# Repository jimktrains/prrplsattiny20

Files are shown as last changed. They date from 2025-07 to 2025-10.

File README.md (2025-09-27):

PRR Position Light Signals based on an ATTiny20
-----------------------------------------------
Thumb for scale.

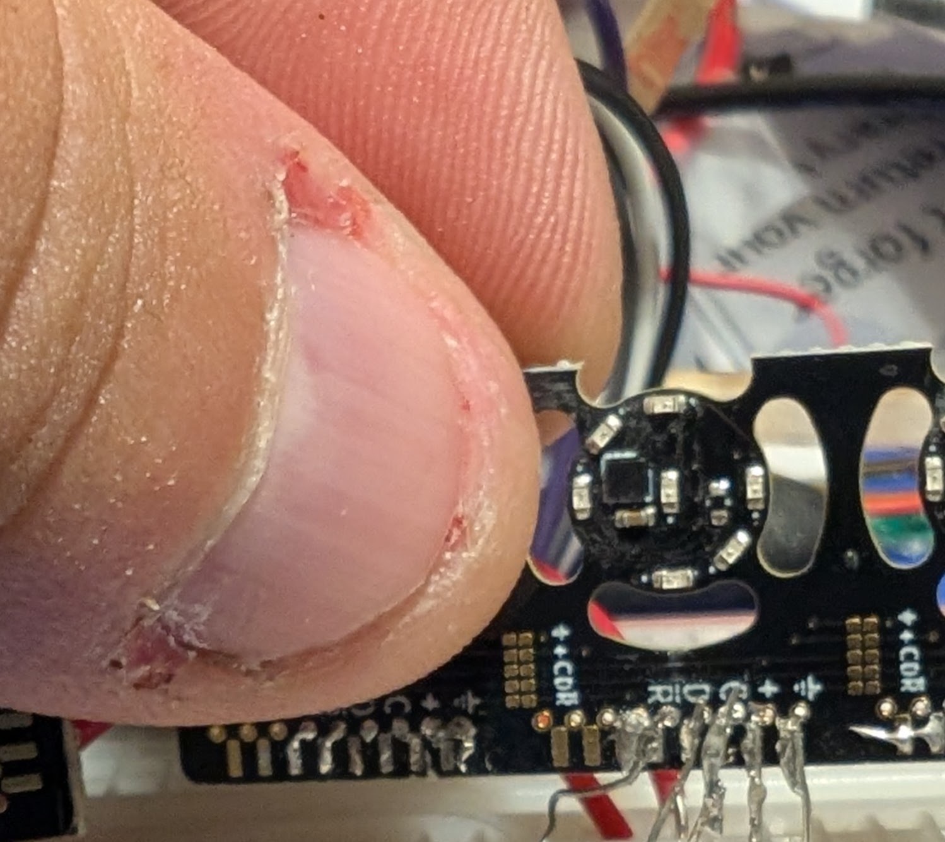
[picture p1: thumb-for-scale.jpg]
Thumb for scale


In Action!

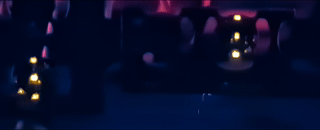
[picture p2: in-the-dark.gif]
In The Dark

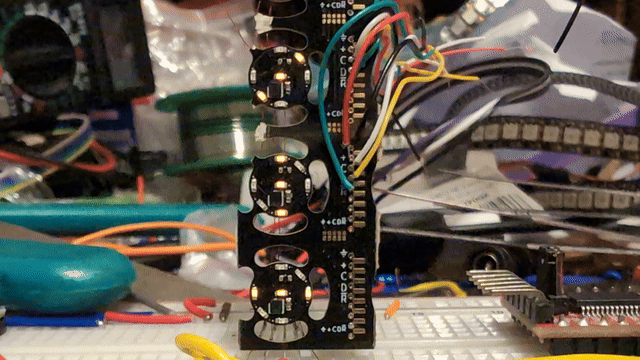
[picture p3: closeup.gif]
Close Up


The Pennsylvania Railroad (PRR), almost uniquely among railroads, used
Position Light Signals (PLS) 
[[1]](https://en.wikipedia.org/wiki/North_American_railroad_signals#Position_light_signals)
[[2]](https://railroadsignals.us/signals/pl/pl.htm). (The Norfolk & Western
used Colored Position Lights (CPL) 
[[2]]([https://railroadsignals.us/signals/pl/pl.htm) which were similar.)

I model [N-Scale](https://en.wikipedia.org/wiki/N_scale) which is 1:160
scale. From scans of PRR plans
[[3]](http://prr.railfan.net/signalstandards/standards.cgi?plan=S-401-D&frame=YES&sortdir=up&sortby=1&rr=all)
the diameter of the signal is 4'4", which becomes 0.325" (8.255mm) for the
scale model.

I've designed the system to use 3 wires: +5V, Ground, and Serial. Serial
data comes in, the first command extracted, and then the remainder of a packet
is retransmitted similar to how WS2812b / NeoPixels work. 

Protocol
========

The serial protocol is 
[Differential Manchester](https://en.m.wikipedia.org/wiki/Differential_Manchester_encoding)
, but kind of overlaid on
a double-baud UART frame, so it always starts with the "0" stop bit.

I moved to this from just a plain software UART as the timing on some of my
signals was off by a large enough amount to throw everything out of sync.
Decoding the differential Manchester packet is much less timing-sensitive.
It runs at 300baud/150bps with 4-bit packets.

A packet starts with an 0x4 followed a sequence of 0x3 for Stop, 0x2 for
Approach, and 0x1 for Clear, 0x0 for all lights off.

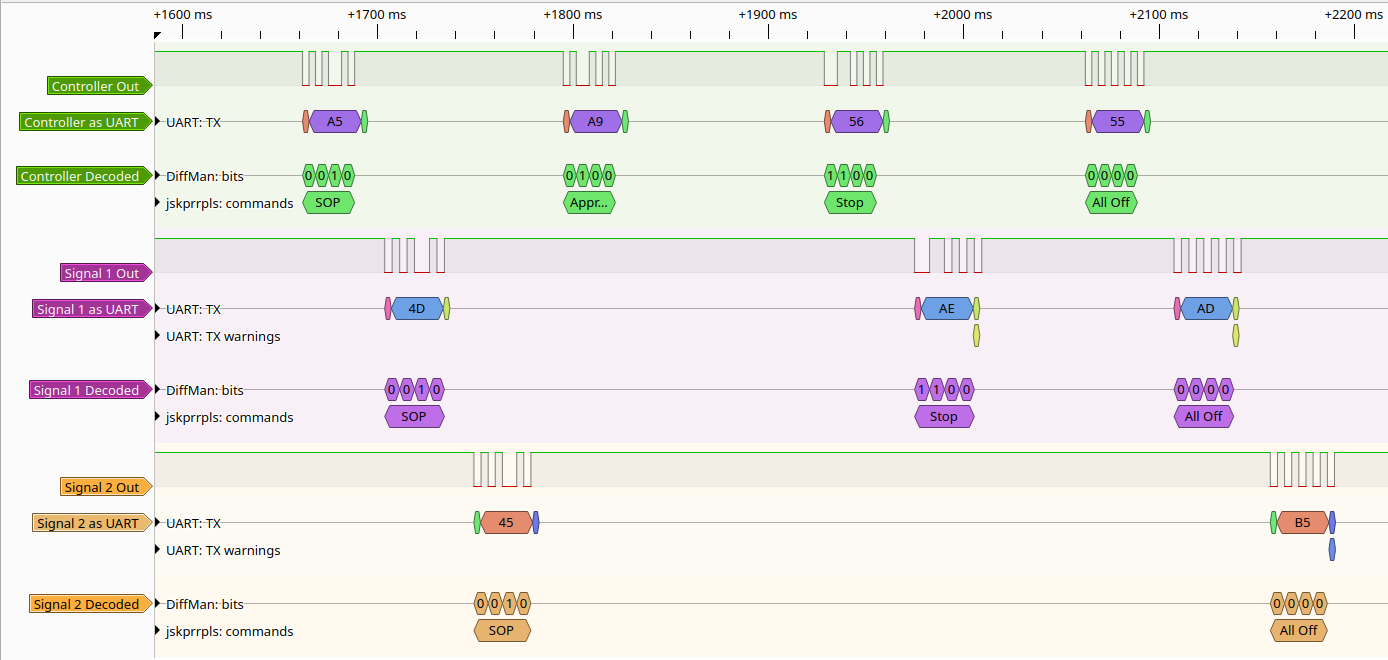
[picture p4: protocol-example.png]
Protocol Example


In this example, the controller sends out a 4-frame packet. Starting with a SOP (Start of Packet) frame, followed
by an Approach, then Stop, then All Off. The first signal dutifully forwards
the SOP frame. The second frame is for it, though, so it does not forward 
that one. The rest of the frames are for subsequent signals, so it forwards
all subsequent frames until a SOP is encountered again. The second signal
does as the first. It forwards the SOP, keeps the frame following the SOP,
and forwards any remaining frames until another SOP is encountered.

Also, note how when interpreted as a UART, the packets coming from the signals
isn't in sync with the baudrate. I'm sure that there's some way to get a more
stable clock on the μC, but it was significantly easier for me to switch to a
more forgiving line coding. 

There also needs to be at least a 20 symbol pause between frames sent. I 
think this has to do with how I decode the frame, but it deserves to be
looked at.

(The visualization is from PulseView/sigrok. I wrote a custom protocol
decoder to help me debug.)

Schematics / PCB
================

### General Notes

I am using an 
[ATTiny20](https://ww1.microchip.com/downloads/en/DeviceDoc/Atmel-8235-8-bit-AVR-Microcontroller-ATtiny20_Datasheet.pdf)
in a 
[WLCSP](https://en.wikipedia.org/wiki/Wafer-level_packaging) package 
(1.56mm&times;1.4mm) with 0.4mm balls, and I'm not sure I can solder that
at my current skill level.) I'm just bemused at it's physical size, even if
it only has 128 bytes of RAM. It fits perfectly in the area available,
allows for components on a single side, and has enough I/O to control
the LEDs individually.

In order to avoid having to place a resistor per
LED, I'm using the pull-up resistors in the microcontroller. Since these
are large-resistance resistors, it limits the brightness of the LEDs. While
the pull-up resistors aren't any specific resistance and can be pretty
variable, the ones within a single chip should be pretty similar. This may
mean that signals visibility near each other may be of different brightness,
but so far it doesn't appear to be a noticeable issue.

The limited brightness is a potential problem, but I'm going to try up the
effective PWM duty cycle. If each light is updated sequentially at the
frequency at which the RX pin is sampled spread over the 7 lights -- 
currently 1200Hz with a 1/7 (14%) duty cycle. Because the LEDs are
charliplexed I am limited in which LEDs I could turn on simultaneously.
However, because I separated out the center light and I think lucked into
arranging the lights in a sensible order I am able to have them on with
100% duty cycle for the 3 basic aspects these display (Stop, Clear, and
Approach). For those aspects I think the current brightness is adequate.

### PCB Notes

The PCB design is fairly simple, and using 4 layers (Signal, +5V+Minimal Signal,
GND, Signal) made routing easier.

To avoid using via-in-pads (and being charged accordingly), there are 3 pins
(balls?) that aren't used. If they had been used, each LED could have been
directly connected to the μC. As such, I was able to control the LEDs
individually by charlieplexing them.

I used a 1.27mm pitch SOIC chip clip as my connectorless connector. (I did
manage to make the through-holes a little too small, so it doesn't attach
as securely as I would have liked.) Eventually I just soldered some THT
resistor legs to these to connect to a breadboard for some of the signal
heads.

When panalized, I added some traces that I can use to interconnect columns
for testing.

### Individual Schematic

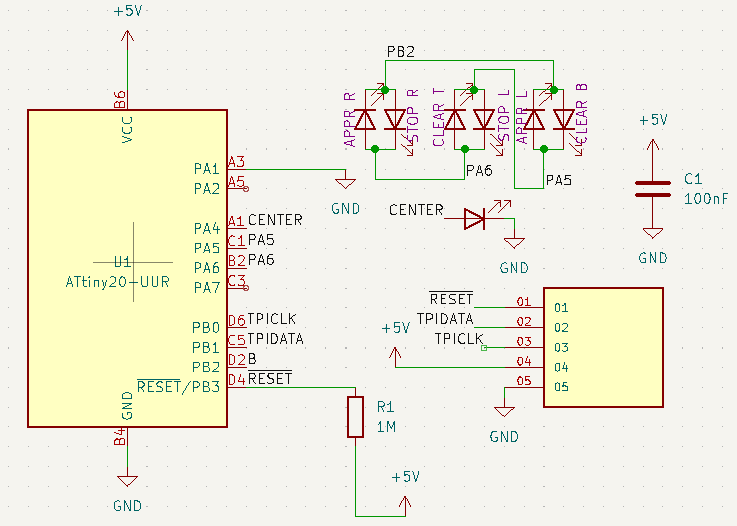
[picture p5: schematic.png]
Individual Schematic


### Front Copper

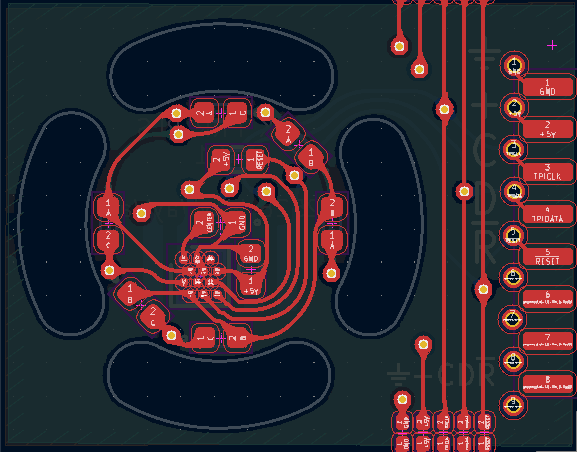
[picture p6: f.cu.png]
F.Cu


### Inner 1 Copper

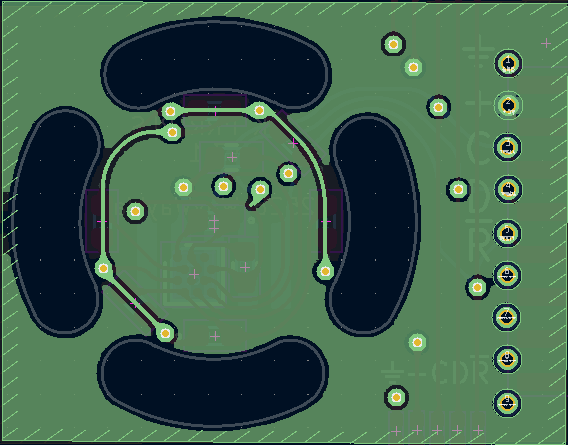
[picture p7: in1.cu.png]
In1.Cu


### Inner 2 Copper

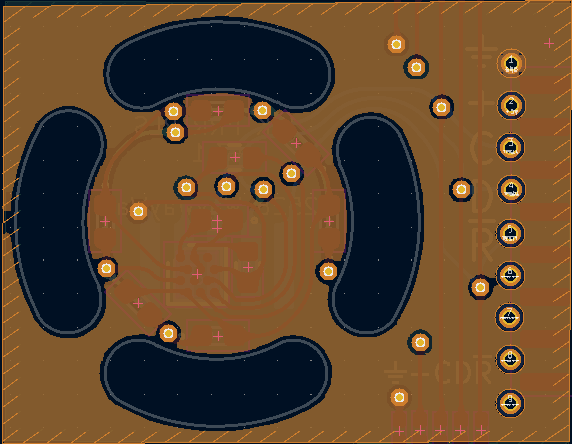
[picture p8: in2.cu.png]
In2.Cu


### Back Copper

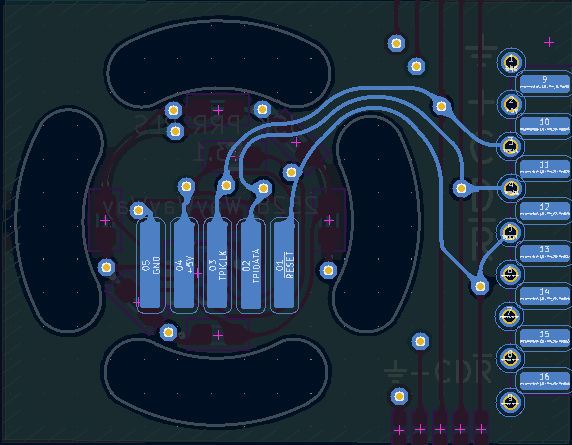
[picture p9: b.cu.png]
B.Cu


Programming and Testing
========================

Here is how I test and program these modules. The Arduino is running [this
sketch](tpi_programmer/) from [Junk +
Arduino](https://junkplusarduino.blogspot.com/p/attiny10-resources.html). I
added a software serial console to it to make testing easier. The FT232RL in
the schematic is actually a breakout board that provides the +5V.

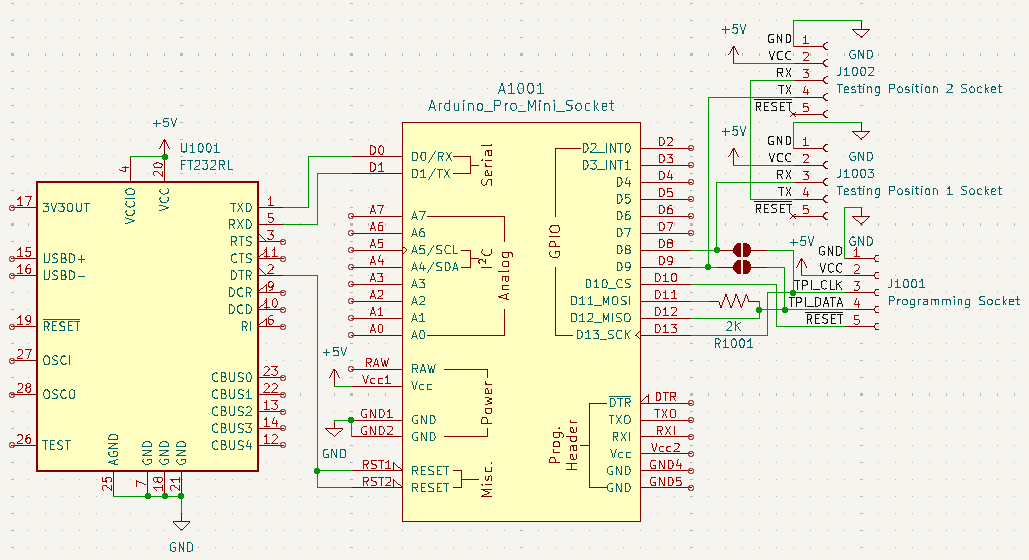
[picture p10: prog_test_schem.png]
Programming and Testing Schematic


My next step is to use 38 gauge (40mil (0.1007mm) diameter) enameled wire to
wire the signals into a wayside signal on a post, and then a signal bridge.

Please excuse my soldering. This is back of what was in the video above.
Just a proof of concept that the enamel wire will work. (Well, more that
I can make it work, e.g. strip it without breaking it and soldering it.)

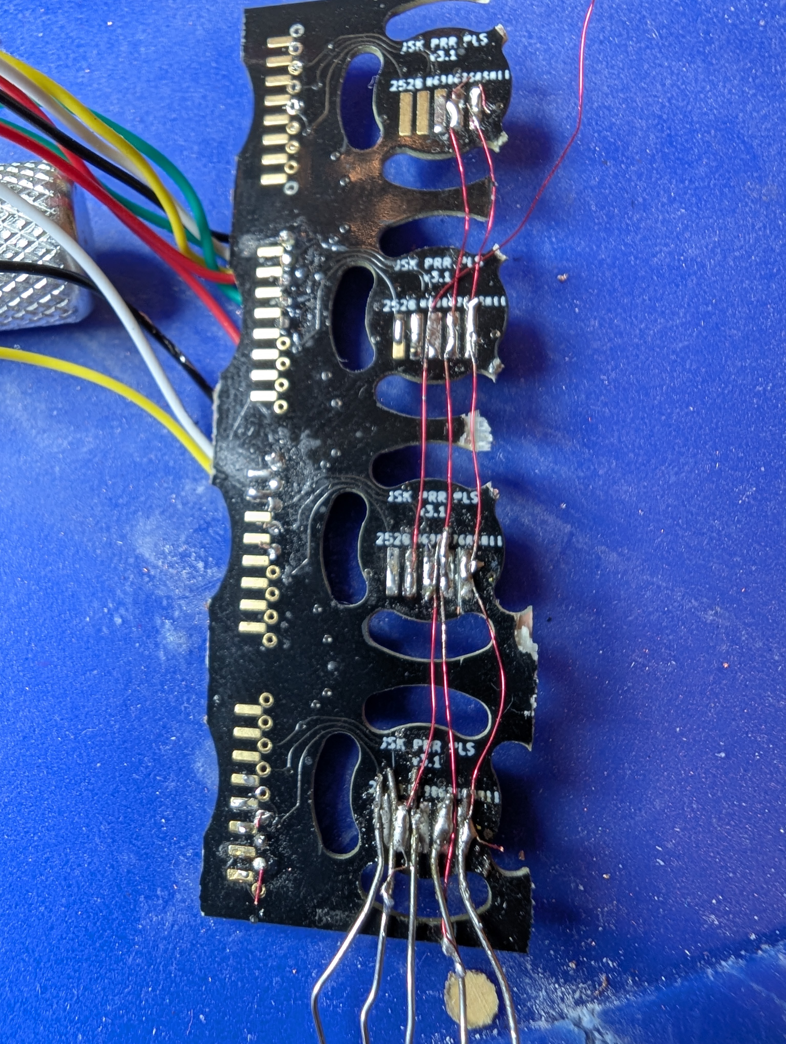
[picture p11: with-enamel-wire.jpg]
with enamel wires


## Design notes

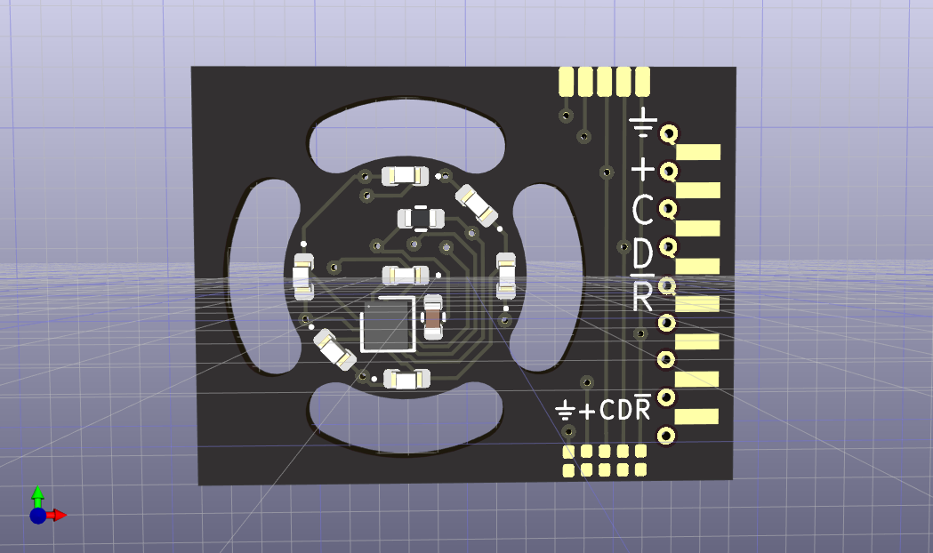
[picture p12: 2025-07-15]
prrplsattiny20.png

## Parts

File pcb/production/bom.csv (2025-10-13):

Designator | Footprint | Quantity | Value | LCSC Part #
C1_25, C1_24, C1_23, C1_22, C1_21, C1_20, C1_19, C1_18, C1_17, C1_16, C1_15, C1_14, C1_13, C1_12, C1_11, C1_10, C1_9, C1_8, C1_7, C1_6, C1_5, C1_4, C1_3, C1_2, C1 | 0402 | 25 | 100nF | C22435938
C1001_25, C1001_24, C1001_23, C1001_22, C1001_21, C1001_20, C1001_19, C1001_18, C1001_17, C1001_16, C1001_15, C1001_14, C1001_13, C1001_12, C1001_11, C1001_10, C1001_9, C1001_8, C1001_7, C1001_6, C1001_5, C1001_4, C1001_3, C1001_2, C1001 | 0402 | 25 | 22μF
D1_25, D1_24, D1_23, D1_22, D1_21, D1_20, D1_19, D1_18, D1_17, D1_16, D1_15, D1_14, D1_13, D1_12, D1_11, D1_10, D1_9, D1_8, D1_7, D1_6, D1_5, D1_4, D1_3, D1_2, D1, D2_25, D2_24, D2_23, D2_22, D2_21, D2_20, D2_19, D2_18, D2_17, D2_16, D2_15, D2_14, D2_13, D2_12, D2_11, D2_10, D2_9, D2_8, D2_7, D2_6, D2_5, D2_4, D2_3, D2_2, D2, D3_25, D3_24, D3_23, D3_22, D3_21, D3_20, D3_19, D3_18, D3_17, D3_16, D3_15, D3_14, D3_13, D3_12, D3_11, D3_10, D3_9, D3_8, D3_7, D3_6, D3_5, D3_4, D3_3, D3_2, D3, D4_25, D4_24, D4_23, D4_22, D4_21, D4_20, D4_19, D4_18, D4_17, D4_16, D4_15, D4_14, D4_13, D4_12, D4_11, D4_10, D4_9, D4_8, D4_7, D4_6, D4_5, D4_4, D4_3, D4_2, D4, D5_25, D5_24, D5_23, D5_22, D5_21, D5_20, D5_19, D5_18, D5_17, D5_16, D5_15, D5_14, D5_13, D5_12, D5_11, D5_10, D5_9, D5_8, D5_7, D5_6, D5_5, D5_4, D5_3, D5_2, D5, D6_25, D6_24, D6_23, D6_22, D6_21, D6_20, D6_19, D6_18, D6_17, D6_16, D6_15, D6_14, D6_13, D6_12, D6_11, D6_10, D6_9, D6_8, D6_7, D6_6, D6_5, D6_4, D6_3, D6_2, D6, D7_25, D7_24, D7_23, D7_22, D7_21, D7_20, D7_19, D7_18, D7_17, D7_16, D7_15, D7_14, D7_13, D7_12, D7_11, D7_10, D7_9, D7_8, D7_7, D7_6, D7_5, D7_4, D7_3, D7_2, D7 | 0402 | 175 | YELLOW LED | C779450
J1_25, J1_24, J1_23, J1_22, J1_21, J1_20, J1_19, J1_18, J1_17, J1_16, J1_15, J1_14, J1_13, J1_12, J1_11, J1_10, J1_9, J1_8, J1_7, J1_6, J1_5, J1_4, J1_3, J1_2, J1 | Tag-Connect_TC2030-IDC-NL_2x03_P1.27mm_Vertical | 25 | Conn_02x08_Counter_Clockwise
J1001_25, J1001_24, J1001_23, J1001_22, J1001_21, J1001_20, J1001_19, J1001_18, J1001_17, J1001_16, J1001_15, J1001_14, J1001_13, J1001_12, J1001_11, J1001_10, J1001_9, J1001_8, J1001_7, J1001_6, J1001_5, J1001_4, J1001_3, J1001_2, J1001, J1002_25, J1002_24, J1002_23, J1002_22, J1002_21, J1002_20, J1002_19, J1002_18, J1002_17, J1002_16, J1002_15, J1002_14, J1002_13, J1002_12, J1002_11, J1002_10, J1002_9, J1002_8, J1002_7, J1002_6, J1002_5, J1002_4, J1002_3, J1002_2, J1002, J1003_25, J1003_24, J1003_23, J1003_22, J1003_21, J1003_20, J1003_19, J1003_18, J1003_17, J1003_16, J1003_15, J1003_14, J1003_13, J1003_12, J1003_11, J1003_10, J1003_9, J1003_8, J1003_7, J1003_6, J1003_5, J1003_4, J1003_3, J1003_2, J1003, J1004_25, J1004_24, J1004_23, J1004_22, J1004_21, J1004_20, J1004_19, J1004_18, J1004_17, J1004_16, J1004_15, J1004_14, J1004_13, J1004_12, J1004_11, J1004_10, J1004_9, J1004_8, J1004_7, J1004_6, J1004_5, J1004_4, J1004_3, J1004_2, J1004, J1005_25, J1005_24, J1005_23, J1005_22, J1005_21, J1005_20, J1005_19, J1005_18, J1005_17, J1005_16, J1005_15, J1005_14, J1005_13, J1005_12, J1005_11, J1005_10, J1005_9, J1005_8, J1005_7, J1005_6, J1005_5, J1005_4, J1005_3, J1005_2, J1005, J1006_25, J1006_24, J1006_23, J1006_22, J1006_21, J1006_20, J1006_19, J1006_18, J1006_17, J1006_16, J1006_15, J1006_14, J1006_13, J1006_12, J1006_11, J1006_10, J1006_9, J1006_8, J1006_7, J1006_6, J1006_5, J1006_4, J1006_3, J1006_2, J1006 | SolderWire-D0.7mm_Drill0.3 | 150 | Conn_01x01
R1_25, R1_24, R1_23, R1_22, R1_21, R1_20, R1_19, R1_18, R1_17, R1_16, R1_15, R1_14, R1_13, R1_12, R1_11, R1_10, R1_9, R1_8, R1_7, R1_6, R1_5, R1_4, R1_3, R1_2, R1 | 0402 | 25 | 1M | C138033
U1_25, U1_24, U1_23, U1_22, U1_21, U1_20, U1_19, U1_18, U1_17, U1_16, U1_15, U1_14, U1_13, U1_12, U1_11, U1_10, U1_9, U1_8, U1_7, U1_6, U1_5, U1_4, U1_3, U1_2, U1 | WLCSP-12_1.403x1.555mm_Layout6x4_P0.4mm_Stagger | 25 | ATtiny20-UUR | C219130

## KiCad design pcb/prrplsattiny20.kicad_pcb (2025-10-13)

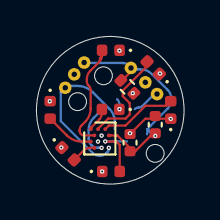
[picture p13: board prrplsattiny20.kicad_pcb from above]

Board: 4 copper layers, 8.2 x 8.2 mm, 18 parts (1 on the bottom side), 12 nets.

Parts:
C1: 100nF; C_0402_1005Metric
C1001: 22μF; C_0402_1005Metric
D1, D2, D3, D4, D5, D6, D7: YELLOW LED; LED_0402_1005Metric
J1: Conn_02x08_Counter_Clockwise; Tag-Connect_TC2030-IDC-NL_2x03_P1.27mm_Vertical
J1001, J1002, J1003, J1004, J1005, J1006: Conn_01x01; SolderWire-D0.7mm_Drill0.3
R1: 1M; R_0402_1005Metric
U1: ATtiny20-UUR; WLCSP-12_1.403x1.555mm_Layout6x4_P0.4mm_Stagger

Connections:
+5V: C1.1, C1001.1, J1.2, J1002.1, J1004.1, R1.2, U1.B6 (VCC)
/A1: D4.2 (A), U1.A1 (PA4)
/A3: D2.2 (A), U1.A3 (PA1)
/A5: D5.2 (A), U1.A5 (PA2)
/B2: D1.2 (A), U1.B2 (PA6)
/C1: D3.2 (A), U1.C1 (PA5)
/D2: D6.2 (A), U1.D2 (PB2)
/Serial_In: J1.4, J1003.1, U1.C3 (PA7)
/TPICLK_SO: J1.3, J1001.1, U1.D6 (PB0)
/TPIDATA: D7.2 (A), J1.1, U1.C5 (PB1)
/~RESET: J1.5, R1.1, U1.D4 (~RESET/PB3)
GND: C1.2, C1001.2, D1.1 (K), D2.1 (K), D3.1 (K), D4.1 (K), D5.1 (K), D6.1 (K), D7.1 (K), J1.6, J1005.1, J1006.1, U1.B4 (GND)

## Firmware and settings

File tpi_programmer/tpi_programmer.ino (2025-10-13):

// ATtiny10Programmer.ino
//
// Brian Doyle, brian@balance-software.com, 2014.09.27
//
// This is a complete rewrite of the ATtiny4/5/9/10 programmer I found here:
// http://junkplusarduino.blogspot.com/p/attiny10-resources.html
// which appears to be the blog of "feynman17'.
//
// Credits for the original code go at least to:
//
// feynman17
// pcm1723
// Keri DuPrey
// Nat Blundelltpi_identify_device
//
// I would like to expressly thank all of the above individuals for their efforts.
// This is my first program for the Arduino and I simply would not have been able
// to learn as much as I have in such a short amount of time had it not been
// for their substantial efforts.  Sincerely, thank you.
//
// While much of this code derives directly from their efforts, it is all new,
// so any errors are mine.  That said, if you use it you take all the responsibility.
// If it eats your hardware or sets your house on fire too bad.
//
// This code is expressly licensed under the MIT License.
//
// This code is both more and less functional than the original, owing
// to the fact I haven't yet ported a few things.
//
// The original code had a few problems.  First, it didn't correctly handle
// the address field of AVRStudio .hex files.  This prevents using .org directives
// to specify where certain chunks of code or data should go.
//
// Second, the original code tended to fail arbitrarily depending on
// how much code I was trying to send over the serial port.  I know now the
// reason it failed was because of serial buffer overruns, but *not* knowing that
// initially was enough for me to start rewriting the code.  You might ask why I
// chose that route instead of trying to modify the original.  I learn better when
// I write things from scratch, but I also had to understand it all before I knew
// for sure what the problem was.  Rewriting it was the fastest way for me to do that.
//
// Now that I have a handle on things I've changed the upload logic so that it
// writes all the serial data into a buffer first and then writes to the ATtiny.
//
// My implementation currently doesn't support ATtiny 20 and 40, at least insofar
// as those chips support 2KB and 4KB flash areas respectively.  Modifying
// this code to support those chips wouldn't be too hard, but as I only have
// ATtiny10's, there's no reason yet for me to do it.
//
// What else don't I have in here at the moment?
//
// High voltage programming
// Fuse setting/clearing
// Quick reset
// Probably some other stuff
//
// How to use this?
//
// Get an Arduino.  I have an Arduino Nano which works great.
// Get an ATtiny10 (get a few, I've fried one already).
// Hook up the Arduino to the ATtiny10 as shown in this diagram:
//
//
//    Arduino                ATtiny10
//    -----------+          +----------------
//    (SS#)  D10 |----------| 6 (RESET#/PB3)
//               |          |
//    (MOSI) D11 |--[R]--+--| 1 (TPIDATA/PB0)
//               |       |  |
//    (MISO) D12 |-------+  |
//               |          |
//    (SCK)  D13 |----------| 3 (TPICLK/PB1)
//    -----------+          +----------------
//
//    -----------+          +----------------
//    (HVP)   D9 |---       | 6 (RESET#/PB3)
//               |          |
//
//  -[R]-  =  2.2kΩ resistor
//
//  2011.12.08:     Original image by pcm1723
//
//  2014.09.26 bd:  The pcm1723 image had resistors on D10, D12, and D13.
//                  Both the Arduino Nano and the ATtiny10 operate at 5V and
//                  are rated at 40mA per pin (ATtiny reference §16.1 p. 115,
//                  Nano via online) so I'm getting rid of all the resistors
//                  except the one on D11 to prevent MISO->MOSI.
//
//
// Note the HVP connection is not necessary, and isn't even supported by this
// program (to do).
// Write some assembly code in AVRStudio for the ATtiny10.
// Build it, then open the .hex file generated by AVRStudio.
// Upload this sketch to the Arduino.
// I use Sublime Text 2 with Stino on my Mac (https://github.com/Robot-Will/Stino),
// and I run AVRStudio under Windows in a VM.  You should use whatever
// Arduino environment makes you happy.
// Once the sketch is uploaded, open the Serial Monitor.
// Set the baud rate to 115,200.
// Type in a question mark (?) and hit enter to see a list of commands.
// Use the 'u' command to start programming the ATtiny10.
// Next copy the entire contents of your .hex file.
// Paste the .hex file content into the Send box of the Serial Monitor and click send.
// Your Arduino should program your ATtiny.
// I've noticed if I do all of this from Windows (even under VMware), I never
// have to pull out the USB cable and reset the Arduino.  It just programs
// the ATtiny10 then my program starts to run.  I can write it over and over again,
// just repeatly using the 'u' command and uploading.  That's nice.
// Congratulations, if you're like me you've spend an absurd amount of time getting
// an LED to blink.
//
// Some other interesting code I wrote in support of my LED color cycling project
// can be found here:
//
// http://jsfiddle.net/16bmnzn8/
//
// The section references sprinkled throughout the comments refer to the
// ATtiny10 datasheet:
//
// http://www.atmel.com/Images/Atmel-8127-AVR-8-bit-Microcontroller-ATtiny4-ATtiny5-ATtiny9-ATtiny10_Datasheet.pdf

#include "./Keypad.h"
#include <SPI.h>
#include <SoftwareSerial.h>

#include "pins_arduino.h"



enum ArduinoPortBBits {
  kPortBSS = 1 << 2,
  kPortBMOSI = 1 << 3,
  kPortBMISO = 1 << 4,
  kPortBSCK = 1 << 5,
};

enum ATtiny4_5_9_10AddressSpace {
  // §5.2
  kTiny4IO = 0x0000,             // 0x0000 - 0x003f
  kTiny4SRAM = 0x0040,           // 0x0040 - 0x005f
  kTiny4Reserved0 = 0x0060,      // 0x0060 - 0x3eff
  kTiny4NVMLock = 0x3f00,        // 0x3f00 - 0x3f01
  kTiny4Reserved1 = 0x3f02,      // 0x3f02 - 0x3f3f
  kTiny4Configuration = 0x3f40,  // 0x3f40 - 0x3f41
  kTiny4Reserved2 = 0x3f42,      // 0x3f42 - 0x3f7f
  kTiny4Calibration = 0x3f80,    // 0x3f80 - 0x3f81
  kTiny4Reserved3 = 0x3f82,      // 0x3f82 - 0x3fbf
  kTiny4DeviceId = 0x3fc0,       // 0x3fc0 - 0x3fc3
  kTiny4Reserved4 = 0x3fc4,      // 0x3fc4 - 0x3fff
  kTiny4Flash = 0x4000,          // 0x4000 - 0x41ff (tiny 4/5), 0x4000 - 0x43ff (tiny 9/10)
};

enum ATtinyType {
  kATtinyUnknown,

  kATtiny4 = 4,
  kATtiny5 = 5,
  kATtiny9 = 9,
  kATtiny10 = 10,
  kATtiny20 = 20,
  kATtiny40 = 40,
};

enum IntelHexFileType {
  kIHTypeData = 0,
  kIHTypeEOF = 1,
  kIHTypeExtSegAddr = 2,
  kIHTypeStartSegAddr = 3,
  kIHTypeExtLinAddr = 4,
  kIHTypeStartLinAddr = 5,
};

enum TPICSS {
  TPIIR = 0x0f,   // §14.7.1
  TPIPCR = 0x02,  // §14.7.2
  TPISR = 0x00,   // §14.7.3

  GT0 = 0x01,                // §14.7.2 guard time bit 0
  GT1 = 0x02,                // §14.7.2 guard time bit 1
  GT2 = 0x04,                // §14.7.2 guard time bit 2
  NVMDisable = 0x00,         // §14.7.3
  NVMEnable = 0x02,          // §14.7.3
  TPIIdentification = 0x80,  // §14.7.1
};

// §14.5
enum TPIInstruction {
  SIN = 0x10,                // serial in from i/o space
  SKEY = 0xe0,               // serial key signaling
  SLD = 0x20,                // serial load from data space
  SLD_postIncrement = 0x24,  // serial load from data space with post increment
  SLDCS = 0x80,              // serial load from control and status space
  SOUT = 0x90,               // serial out to i/o space
  SST = 0x60,                // serial store to data space
  SST_postIncrement = 0x64,  // serial store to data space with post increment
  SSTCS = 0xc0,              // serial store to control and status space
  SSTPR_high = 0x69,         // serial store to pointer register high byte
  SSTPR_low = 0x68,          // serial store to pointer register low byte
};

enum TPINVM {
  NVMCMD = 0x33,  // §15.7.2
  NVMCSR = 0x32,  // §15.7.1

  NVMBusy = 0x80,          // §15.7.1
  NVMChipErase = 0x10,     // §15.7.2
  NVMNop = 0x00,           // §15.7.2
  NVMSectionErase = 0x14,  // §15.7.2
  NVMWordWrite = 0x1d,     // §15.7.2
};

ATtinyType gATtinyType;
uint16_t gTPIPointer;

bool tpi_memory_read(uint8_t &data, bool postIncrement = true, bool updateGTPIPointer = true);
bool tpi_memory_write(uint8_t data, bool postIncrement = true, bool updateGTPIPointer = true);


uint16_t get_free_memory() {
  uint16_t v;
  extern uint16_t __heap_start, *__brkval;

  return (uint16_t)&v - (__brkval ? (uint16_t)&__heap_start : (uint16_t)__brkval);
}

#define SOFT_UART_RX A3
#define SOFT_UART_TX A2
#define SOFT_UART_BAUD 300

SoftwareSerial soft_uart = SoftwareSerial(SOFT_UART_RX, SOFT_UART_TX);

void setup() {
  tristate_arduino_spi();  // so we can test the tiny at power on

  Serial.begin(115200);
  soft_uart.begin(SOFT_UART_BAUD);
  disableSoftUart();
}

void disableSoftUart() {
  soft_uart.stopListening();
  pinMode(SOFT_UART_RX, INPUT);
  pinMode(SOFT_UART_TX, INPUT);
}

void enableSoftUart() {
  pinMode(SOFT_UART_RX, INPUT);
  pinMode(SOFT_UART_TX, OUTPUT);
  digitalWrite(SOFT_UART_TX, HIGH);
  soft_uart.listen();
}

void soft_uart_console() {
  int16_t c;
  enableSoftUart();
  Serial.println("Console started!");
  while (1) {
    c = soft_uart.read();
    if (c != -1) {
      Serial.write(c);
    }
    c = Serial.read();
    if (c != -1) {
      soft_uart.write(c);
      if (c == 27) {
        break;
      }
    }
  }
  disableSoftUart();
}

bool show_prompt = true;
char *msg = malloc(5);

uint8_t int_to_dman[16] = {
  0x55,
  0xaa,
  0xa9,
  0x56,
  0xa5,
  0x5a,
  0x59,
  0xa6,
  0x95,
  0x6a,
  0x69,
  0x96,
  0x65,
  0x9a,
  0x99,
};

uint8_t cycle_signals = 0;
uint32_t last_cycle_millis = 0;
auto last_keypress = 0;
void loop() {
  Keypad kpad(5, 9);
  memset(msg, 0, 5);
  if (show_prompt) {
    Serial.print(F("Command [d,e,i,m,u,v,s,?] > "));
  }
  show_prompt = true;

  while (Serial.available() < 1) {
    auto k = kpad.scan();
    if (k && k != last_keypress) {
      memset(msg, 0, 5);
      cycle_signals = 0;
      last_cycle_millis = -1;

      Serial.print("Keypad press: ");
      Serial.print(k);
      Serial.print(" ");
      Serial.print(k == Keypad::KEY_1);
      Serial.print(" ");
      Serial.print(k == Keypad::KEY_2);
      Serial.print(" ");
      Serial.print(k == Keypad::KEY_3);
      Serial.print(" ");


      msg[0] = '!';
      switch (k) {
        case Keypad::KEY_1:
          msg[1] = 'S';
          Serial.println("0 STOP from keypad");
          break;
        case Keypad::KEY_2:
          msg[1] = 'A';
          Serial.println("0 APPR from keypad");
          break;
        case Keypad::KEY_3:
          msg[1] = 'C';
          Serial.println("0 CLEAR from keypad");
          break;
        case Keypad::KEY_4:
          msg[2] = 'S';
          Serial.println("1 STOP from keypad");
          break;
        case Keypad::KEY_5:
          msg[2] = 'A';
          Serial.println("1 APPR from keypad");
          break;
        case Keypad::KEY_6:
          msg[2] = 'C';
          Serial.println("1 CLEAR from keypad");
          break;
        case Keypad::KEY_7:
          msg[3] = 'S';
          Serial.println("2 STOP from keypad");
          break;
        case Keypad::KEY_8:
          msg[3] = 'A';
          Serial.println("2 APPR from keypad");
          break;
        case Keypad::KEY_9:
          msg[3] = 'C';
          Serial.println("2 CLEAR from keypad");
          break;
        case Keypad::KEY_0:
          cycle_signals = 1;
          last_cycle_millis = millis() - 3000;
          Serial.println("cycle from keypad");
          break;

        default: break;
      }
    }
    last_keypress = k;
    if (cycle_signals && ((last_cycle_millis - millis()) > 2000)) {
      Serial.print("cycle_signals=");
      Serial.println(cycle_signals);
      msg[1] = ((cycle_signals + 1) % 3) + 1;
      msg[2] = ((cycle_signals + 2) % 3) + 1;
      msg[3] = ((cycle_signals + 3) % 3) + 1;
      cycle_signals = ((cycle_signals + 1) % 3) + 1;
    }
    if (msg[1] || msg[2] || msg[3]) {
      msg[0] = '!';
      enableSoftUart();
      delay(100);
      Serial.print("Sending: ");
      for (int i = 0; i < 4; i++) {
        auto j = int_to_dman[0x5];
        if (msg[i] == 'C') {
          j = int_to_dman[0x1];
        } else if (msg[i] == 'A') {
          j = int_to_dman[0x2];
        } else if (msg[i] == 'S') {
          j = int_to_dman[0x3];
        } else if (msg[i] == '!') {
          j = int_to_dman[0x4];
        } else if (msg[i] < 0xf && msg[i] != 0) {
          j = int_to_dman[msg[i]];
        }
        soft_uart.write(j);
        Serial.print(i);
        Serial.print(":");
        Serial.print(msg[i]);
        Serial.print(":");
        Serial.print(j, HEX);
        Serial.print(" ");
        delay(200);
      }
      memset(msg, 0, 5);
      disableSoftUart();
      Serial.println();
    }
  }


  auto r = Serial.read();
  switch (r) {
    case 'd':
    case 'D': tpi_dump_memory(); break;
    case 'e':
    case 'E': tpi_chip_erase(); break;
    case 'i':
    case 'I': tpi_identify_device(); break;
    case 'm':
    case 'M': print_free_memory(); break;
    case 'u':
    case 'U': upload_program(); break;
    case 'v':
    case 'V': print_version(); break;
    case 's':
    case 'S': soft_uart_console(); break;
    case ' ':
    case '\t':
    case '\r':
    case '\n': show_prompt = false; break;

    default:
      {
        Serial.println(F("Commands:"));
        Serial.println(F("D: Dump memory"));
        Serial.println(F("E: Erase memory"));
        Serial.println(F("I: Identify device"));
        Serial.println(F("M: Print free memory"));
        Serial.println(F("U: Upload program"));
        Serial.println(F("V: Print version"));
        Serial.println(F("S: Serial Console(RX=A3 TX= BAUD=300 8N1)"));
        Serial.println(F("?: Help"));
      }
      break;
  }
}

void print_free_memory() {
  Serial.print(F("Free memory: "));
  Serial.print(get_free_memory());
  Serial.println(F(" bytes"));
}

void print_hex(uint16_t value, int8_t nibbles) {
  while (--nibbles > 0) {
    if (value >> nibbles * 4 & 0x0f) break;  // if msb is != 0

    Serial.print(F("0"));
  }

  Serial.print(value, HEX);
}

void print_version() {
  Serial.println(F("Version 1.0"));
}

void tristate_arduino_spi() {
  const uint8_t kPortBTriState = ~(kPortBSS | kPortBMOSI | kPortBMISO | kPortBSCK);

  DDRB &= kPortBTriState;  // tri-state SPI so ATtiny can be tested
  PORTB &= kPortBTriState;
}

// I had tons of failures trying to write the ATtiny10 while
// reading a hex file from the Serial Monitor.  The problem is
// that the serial buffer gets data faster than the TPI code
// can write it, so the serial buffer overflows and the write
// fails.  To deal with this, I now read the hex file from the
// serial port quickly into a buffer, decoding it only as much
// as is necessary to keep track of the data, the address to
// write to, and the length of data to write.  After I've acquired
// the whole file I then write it to the ATtiny.
//
// Here's a little program I wrote to color cycle an RGB LED with
// an ATtiny10.  It's hooked up like so:
//
// LED_R ---[R]--- ATtiny10_PB0
// LED_G ---[R]--- ATtiny10_PB1
// LED_B ---[R]--- ATtiny10_PB2
//
// :020000020000FC
// :1000000000E00EBF0FE50DBF00E018ED1CBF06BFFE
// :1000100007E001B9000000E002B9B1E4A0E0D1E4DA
// :10002000C5E5F1E4E6EA0DD020E030E011D03395EB
// :10003000363419F4203009F4F6CF3030B9F723956F
// :10004000F5CF7C9188819081A395C395E395089520
// :100050000F931F9301E010E0701708F011608017F4
// :1000600008F01260901708F0146012B9039599F720
// :060070001F910F9108959D
// :100100007F8285888B8F9295989B9EA1A4A7AAAD8C
// :10011000B0B3B6B8BBBEC1C3C6C8CBCDD0D2D5D79D
// :10012000D9DBDDE0E2E4E5E7E9EBECEEEFF1F2F458
// :10013000F5F6F7F8F9FAFBFBFCFDFDFEFEFEFEFE10
// :10014000FFFEFEFEFEFEFDFDFCFBFBFAF9F8F7F6F6
// :10015000F5F4F2F1EFEEECEBE9E7E5E4E2E0DDDB0C
// :10016000D9D7D5D2D0CDCBC8C6C3C1BEBBB8B6B324
// :10017000B0ADAAA7A4A19E9B9895928F8B888582EB
// :100180007F7C7976736F6C696663605D5A575451F2
// :100190004E4B484643403D3B383633312E2C2927C1
// :1001A0002523211E1C1A1917151312100F0D0C0AE6
// :1001B000090807060504030302010100000000000E
// :1001C0000000000000000101020303040506070807
// :1001D000090A0C0D0F1012131517191A1C1E2123D2
// :1001E0002527292C2E313336383B3D404346484B9A
// :1001F0004E5154575A5D606366696C6F7376797CB3
// :00000001FF

void upload_program() {
  uint16_t address, w;
  uint8_t *buffer = NULL, length, *p, *q, type;
  bool success = false;

  // The page size of ATtiny4,5,9,10 is 16 bytes (§15.3.2).
  // AVRStudio generates Intel .hex files with 16-byte data rows
  // in most cases, though they can be smaller.  The buffer allocation
  // here is wide enough to receive 64 rows of 16 bytes each, plus
  // a length byte and an address word, which would be what AVRStudio
  // should output if all 1024 bytes of the ATtiny9,10 memory is filled.
  // I don't expect this to overrun in most cases but it is possible if
  // somehow the .hex file contains lots of smaller-than-page-sized rows.
  // In that case I recommend writing a small python script or similar
  // to preprocess the .hex file and convert it into longer rows.
  // The Intel hex file format is here:
  // https://en.wikipedia.org/wiki/Intel_HEX

  if (!(p = buffer = (uint8_t *)malloc(64 * (1 + 2 + 16)))) {
    Serial.println("Could not allocate enough memory");
    goto done;
  }

  Serial.println(F("Upload hex file content to serial monitor"));

  int databytesread = 0;
  int bytesconsumed = 0;
  int skipped = 0;
  do {
    while (serial_read() != ':') skipped++;

    length = serial_decode_byte();
    bytesconsumed++;
    bytesconsumed++;
    address = (uint16_t)serial_decode_byte() << 8;
    bytesconsumed++;
    bytesconsumed++;
    address |= serial_decode_byte();
    bytesconsumed++;
    bytesconsumed++;
    type = serial_decode_byte();
    bytesconsumed++;
    bytesconsumed++;

    if (length) {
      if (type == kIHTypeData) {
        *p++ = length;
        *p++ = address >> 8 & 0xff;
        *p++ = address & 0xff;

        while (length--) {
          *p++ = serial_decode_byte();
          bytesconsumed++;
          bytesconsumed++;
          databytesread++;
          databytesread++;
        }
      } else {
        while (length--) {
          serial_decode_byte();
          bytesconsumed++;
          bytesconsumed++;
        }
      }
    }

    serial_decode_byte();
    bytesconsumed++;
    bytesconsumed++;  // consume checksum
  } while (type != kIHTypeEOF);

  Serial.println(F("Upload complete"));
  Serial.println(bytesconsumed);
  Serial.println(databytesread);
  Serial.println(skipped);
  tpi_chip_erase();

  Serial.println(F("Writing flash"));

  tpi_enable();

  for (q = buffer; q < p;) {
    length = *q++;
    address = (uint16_t)*q++ << 8;
    address |= *q++;

    print_hex(length, 2);
    Serial.print(F(" "));
    print_hex(address, 4);
    Serial.print(F(" "));

    address |= kTiny4Flash;

    if (address & 1) {
      address &= ~1;
      print_hex(*q, 2);
      w = 0xff00 | *q++;
      if (!tpi_memory_write_word(address, w)) goto done;
      address += 2;
      --length;
    }
    for (; length > 1; address += 2, length -= 2) {
      print_hex(*q, 2);
      w = (uint16_t)*q++ << 8;
      print_hex(*q, 2);
      w |= *q++;
      if (!tpi_memory_write_word(address, w)) goto done;
    }
    if (length) {
      print_hex(*q, 2);
      w = (uint16_t)*q++ << 8 | 0xffu;
      if (!tpi_memory_write_word(address, w)) goto done;
    }

    Serial.println(F(" OK"));
  }

  Serial.println(F("Done"));

  success = true;

done:

  if (!success) Serial.println(F("Upload to ATtiny failed"));

  if (buffer) free(buffer);

  tpi_disable();
}

uint8_t serial_decode_byte() {
  uint8_t b0, b1;

  b0 = serial_read();
  b1 = serial_read();

  return unhex(b0, b1);
}

uint8_t serial_read() {
  while (Serial.available() < 1)
    ;

  return Serial.read();
}

// converts two chars hexadecimal characters to the byte they represent
uint8_t unhex(uint8_t high, uint8_t low) {
  uint8_t b;

  b = (high >= '0' && high <= '9' ? high - '0' : (high & ~0x20) - 'A' + 0xa) << 4;
  b |= low >= '0' && low <= '9' ? low - '0' : (low & ~0x20) - 'A' + 0xa;

  return b;
}

// ATtiny TPI (Tiny Programming Interface) (§14 pp. 95+)

bool tpi_chip_erase() {
  tpi_enable();

  // §15.4.3.1
  // 1. write the CHIP_ERASE command to the NVMCMD register:
  tpi_io_write(NVMCMD, NVMChipErase);

  // 2. Start the erase operation by writing a dummy byte to
  // the high byte of any word location inside the code section
  tpi_set_pointer(kTiny4Flash + 1);
  tpi_memory_write(0x1);

  // 3. Wait until the NVMBSY bit has been cleared
  if (tpi_nvm_wait()) Serial.println(F("Chip erased"));
  else Serial.println(F("Chip erase failed"));

  tpi_disable();
}

bool tpi_css_read(uint8_t address, uint8_t &data) {
  // §14.5.6
  tpi_serial_write(SLDCS | address);

  return tpi_serial_read(data);
}

void tpi_css_write(uint8_t address, uint8_t data) {
  // §14.5.7
  tpi_serial_write(SSTCS | address);
  tpi_serial_write(data);
}

void tpi_disable() {
  tpi_css_write(TPISR, NVMDisable);

  digitalWrite(SS, HIGH);  // release RESET
  delay(1);                // tRST min = 400 ns @ Vcc = 5 V

  SPI.end();

  tristate_arduino_spi();
}
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

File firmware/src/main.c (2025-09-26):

/*
 * Copyright 2025 jsk AGPL3
 *
 * File:   main.c
 * Author: jim
 *
 * Created on July 8, 2025, 1:19 AM
 */

#include <avr/interrupt.h>
#include <avr/io.h>
#include <avr/pgmspace.h>
#include <stdint.h>

// #define F_CPU 8000000

#define SOFT_BAUD 300
#define RX_PIN PB0
#define TX_PIN PB1
// #include "./soft_uart.h"
#include "./dman.h"

#define EP_A PA5
#define EP_B PA6
#define EP_C PB2
#define EP_CENTER PA4

#define EP_A_FLAG (1 << EP_A)
#define EP_B_FLAG (1 << EP_B)
#define EP_C_FLAG (1 << EP_C)
#define EP_CENTER_FLAG (1 << EP_CENTER)

#define EP_PORTA (EP_A_FLAG | EP_B_FLAG | EP_CENTER_FLAG)
#define EP_PORTB (EP_C_FLAG)

/*
 * LEDs are connected to PA5, PA6, and PB2.
 * Center LED is PA4 connected to ground at the cathode.
 * Use the internal pull up resistors to power them.
 */
#define STOP_1 0x65
#define STOP_2 0x62
#define APPR_1 0x26
#define APPR_2 0x25
#define CLEAR_1 0x52
#define CLEAR_2 0x56
#define CENTER 0x04
#define ALLOFF 0x00

#define STOP_1_BIT 0
#define STOP_2_BIT 1
#define APPR_1_BIT 2
#define APPR_2_BIT 3
#define CLEAR_1_BIT 4
#define CLEAR_2_BIT 5
#define CENTER_BIT 6

#define STOP_1_FLAG (1 << STOP_1_BIT)
#define STOP_2_FLAG (1 << STOP_2_BIT)
#define APPR_1_FLAG (1 << APPR_1_BIT)
#define APPR_2_FLAG (1 << APPR_2_BIT)
#define CLEAR_1_FLAG (1 << CLEAR_1_BIT)
#define CLEAR_2_FLAG (1 << CLEAR_2_BIT)
#define CENTER_FLAG (1 << CENTER_BIT)

#define STOP_ASP (STOP_1_FLAG | STOP_2_FLAG | CENTER_FLAG)
#define APPR_ASP (APPR_1_FLAG | APPR_2_FLAG | CENTER_FLAG)
#define CLEAR_ASP (CLEAR_1_FLAG | CLEAR_2_FLAG | CENTER_FLAG)

const uint8_t PROGMEM lightidx[7] = {STOP_1,  STOP_2,  APPR_1, APPR_2,
                                     CLEAR_1, CLEAR_2, CENTER};

#define INIT_SEQ_LEN 3
const uint8_t PROGMEM init_seq[INIT_SEQ_LEN] = {
    STOP_ASP,     APPR_ASP,    CLEAR_ASP};

uint8_t lightson = ALLOFF;
uint8_t prevlightson = ALLOFF;
uint8_t cur_light_bit = 6;

void led_all_off() {
  // Put All LEDs into z state
  // i.e. input with no pull-up
  PUEA &= ~EP_PORTA;
  PUEB &= ~EP_PORTB;
  DDRA &= ~EP_PORTA;
  DDRB &= ~EP_PORTB;
}

void light_led(uint8_t light) {
  uint8_t source = 0x0f & light;
  uint8_t sink = (0xf0 & light) >> 4;

  led_all_off();

  PUEB |= (source == 2) << 2;
  PUEA |= (source != 2 && source != 0) << source;

  DDRB |= (sink == 2) << 2;
  DDRA |= (sink != 2 && sink != 0) << sink;
}

void update_lights() {
  if (lightson == CLEAR_ASP) {
    if (prevlightson != lightson) {
      led_all_off();
      PUEB |= (1 << 2);
      PUEA |= (1 << 6) | (1 << 4);

      DDRA |= (1 << 5);
    }
  } else if (lightson == APPR_ASP) {
    if (prevlightson != lightson) {
      led_all_off();
      PUEA |= (1 << 6) | (1 << 5) | (1 << 4);

      DDRB |= (1 << 2);
    }
  } else if (lightson == STOP_ASP) {
    if (prevlightson != lightson) {
      led_all_off();
      PUEB |= (1 << 2);
      PUEA |= (1 << 5) | (1 << 4);

      DDRA |= (1 << 6);
    }
  } else {
    if (cur_light_bit == 6) {
      cur_light_bit = 0;
    } else {
      cur_light_bit += 1;
    }
    if (lightson & (1 << cur_light_bit)) {
      light_led(lightidx[cur_light_bit]);
    }
  }
  prevlightson = lightson;
}

#define TOGGLE_TX_ON_TIMER 0
#define CYCLE_ASPECTS_ONLY 0

int main(void) {
  // Init LEDs Off
  light_led(ALLOFF);
  // Set the LED pins to be a sink/ground when set as output.
  PORTA &= ~EP_PORTA;
  PORTB &= ~EP_PORTB;

  setup_timer(SOFT_BAUD);

  // Set DDR for Rx and Tx Pins
  DDRB |= ((0 << RX_PIN) | (1 << TX_PIN));
  // UART lines are pulled high by default
  PORTB |= (1 << TX_PIN);

  lightson = STOP_ASP;

  // I'm looping instead of using an interrupt because at 300 baud @ 4x
  // subsamples I only have something like 6600 cycles.
  //     (1000000 cycles / sec) / (1200 symbols / sec)
  //       833 cycles / symbol
  // At 1200 baud that's only around 208 cycles.
  //
  // Since before writing any of this I was unsure of exactly how long the
  // soft uart and LED charliplexing routines will take, I decided to just
  // put everything into one large loop in order to not have the overhead
  // of jumping to and out of the interrupt. It's probably a bit of a
  // needless "optimization", but it's what I have and have tested.

  uint16_t cycle_count = 0;
  uint16_t cycle_stage = 0;
  while (1) {
    if (timer_tick()) {
      update_lights();

      if (CYCLE_ASPECTS_ONLY) {
        cycle_count++;
        if ((cycle_count & 0xff) == 0xff) {
          cycle_stage++;
          lightson = init_seq[cycle_stage % INIT_SEQ_LEN];
        }
      }

      listen();

      if (TOGGLE_TX_ON_TIMER) {
        PORTB ^= (1 << TX_PIN);
      } else {
        send();
      }

      if (new_next_to_tx && tx_ccount == 0) {
        new_next_to_tx = 0;
        new_tx = 1;
        tx_buf = next_to_tx;
      }
      if (new_last_recv) {
        new_last_recv = 0;
        // Our command is right after the packet start, so we don't
        // retransmit it.
        if (last_recv_packet_start) {
          last_recv_packet_start = 0;
          if (!CYCLE_ASPECTS_ONLY) {
            if (last_recv == 'S' || last_recv == 0x03) {
              lightson = STOP_ASP;
            } else if (last_recv == 'A' || last_recv == 0x02) {
              lightson = APPR_ASP;
            } else if (last_recv == 'C' || last_recv == 0x01) {
              lightson = CLEAR_ASP;
            } else if (last_recv >= 0x80) {
              lightson = last_recv;
            } else {
              lightson = ALLOFF;
            }
          }
        } else {
          new_next_to_tx = 1;
          next_to_tx = last_recv;
        }

        if (last_recv == '!' || last_recv == 0x04) {
          last_recv_packet_start = 1;
        }
      }
    }
  }
}

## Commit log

2025-07-15 adding in the kicad pcb
    [prrplsattiny20.kicad_pcb, prrplsattiny20.kicad_sch, prrplsattiny20_kikit.kicad_pcb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]
2025-07-15 note about looping vs interrupt
2025-09-23 Updating the README
    [testcircuit.kicad_pcb, testcircuit.kicad_sch]
2025-09-23 show not-connected in test circuit
    [testcircuit.kicad_sch]
2025-09-23 removing testcircuit empty dir
    [testcircuit.kicad_pcb, testcircuit.kicad_sch]
2025-09-23 make the common aspects brighter
    [prrplsattiny20.kicad_sch]
2025-09-23 adding schematics to README
    [prrplsattiny20.kicad_sch]
2025-09-26 switching to a differential manchester coding for the comms protocol
2025-10-13 v2 of the pcb
    [bom.csv, designators.csv, positions.csv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]
2025-10-14 adding msg when resetting
    [testlights.py]
2025-10-14 experimenting with a new async encoding
    [CPPLINT.cfg]
2025-10-14 better heuristic to guess bits
    [CPPLINT.cfg]
